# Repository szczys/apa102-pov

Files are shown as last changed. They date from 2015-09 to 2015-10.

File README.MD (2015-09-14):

APA102-POV
==========

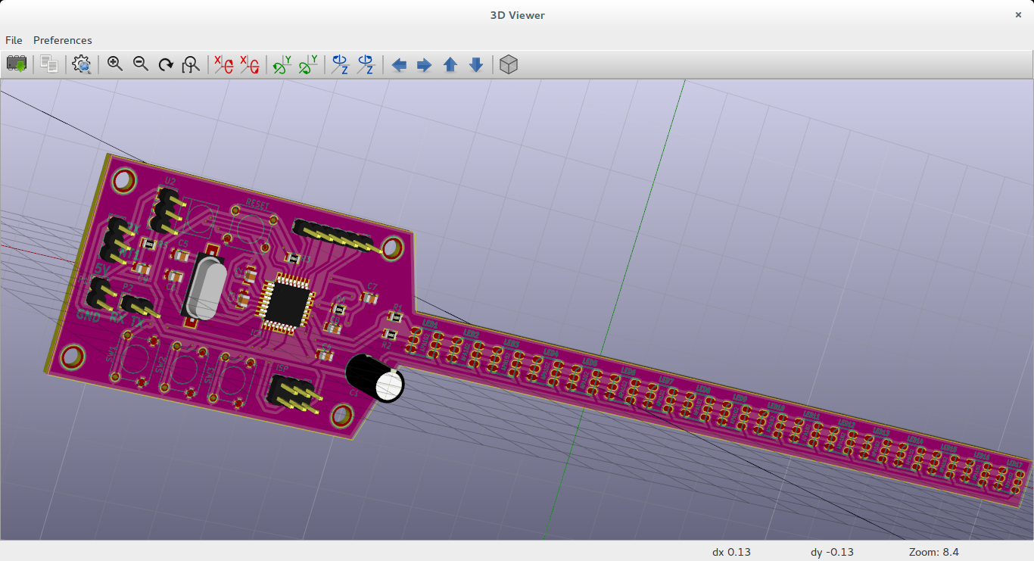
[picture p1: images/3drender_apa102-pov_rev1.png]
3D Render of APA102-POV board Revision 1


This is a persistence of vision display using the APA102 RGB LED modules. I whipped this design up on the spot at Anool Mahidharia's KiCAD workshop (I hadn't relaly planned ahead to have a design ready). It is untested and definitely a work in progress.

Features:
---------

* 17 RGB Pixels (2 rows of 5x7 characters with a row in between and on either edge)
* IR receiver to issue commands as the display spins
* Hall effect sensor to know precisely where/when each revolution begins

TODO:
-----

* Figure out a method to spin this display
* Find a 5V supply for this board
* Write the code

Future Additions:
-----------------

* I broke out RX/TX pins. It would be fun to add an ESP8266 module to make it WiFi connected
* Power transfer from the base which probably means I need a second regulator circuit

License:
--------

Hardware design is by Mike Szczys and licensed [CC-BY-SA 3.0](https://creativecommons.org/licenses/by-sa/3.0/us/)

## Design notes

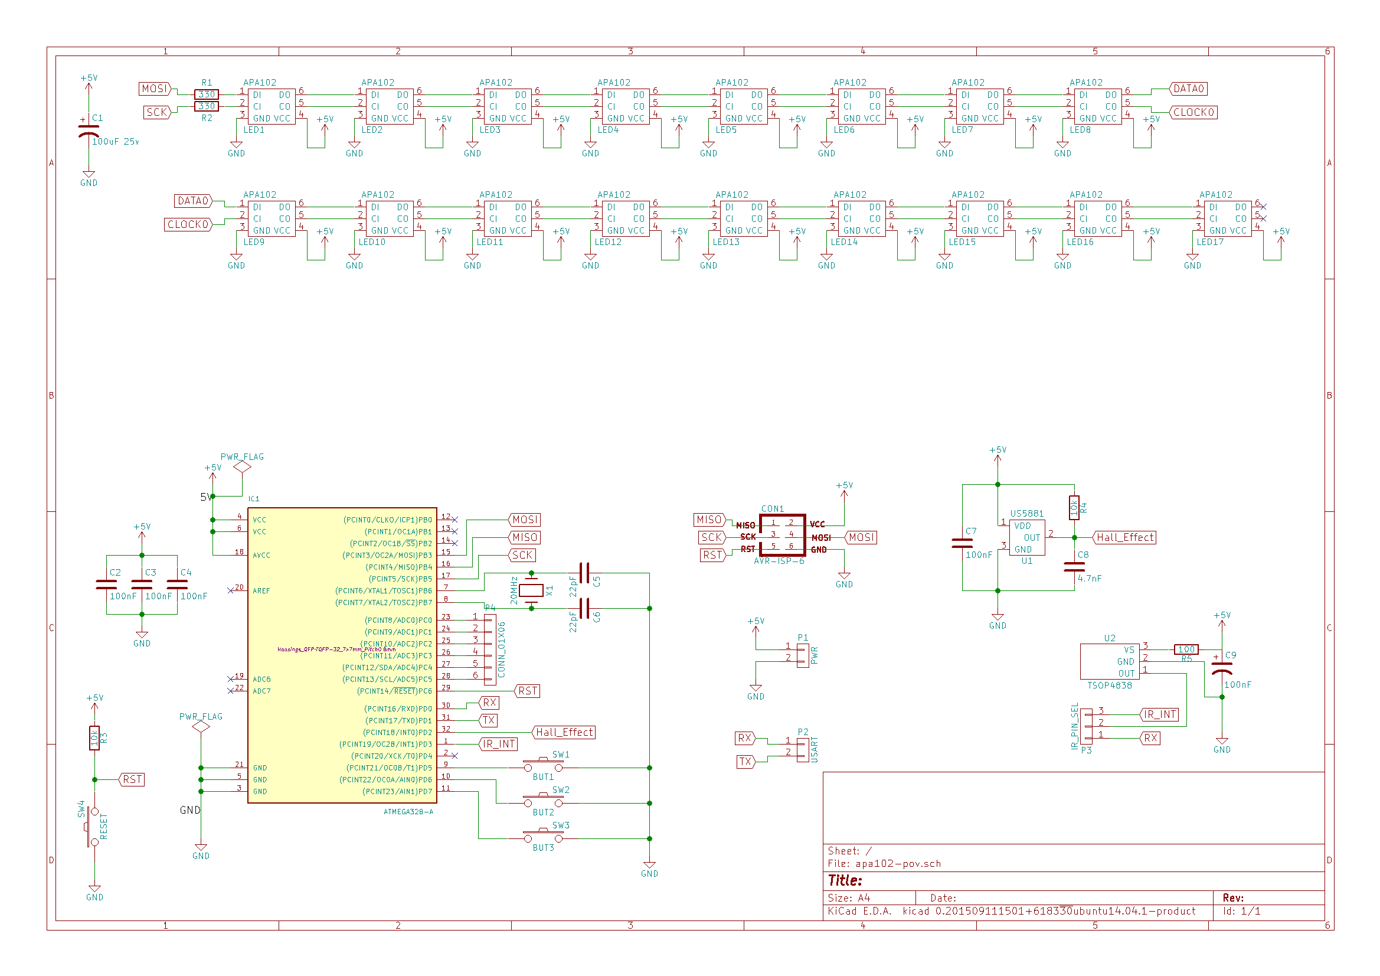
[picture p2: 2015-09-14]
images/schematic_apa102-pov_rev1.png

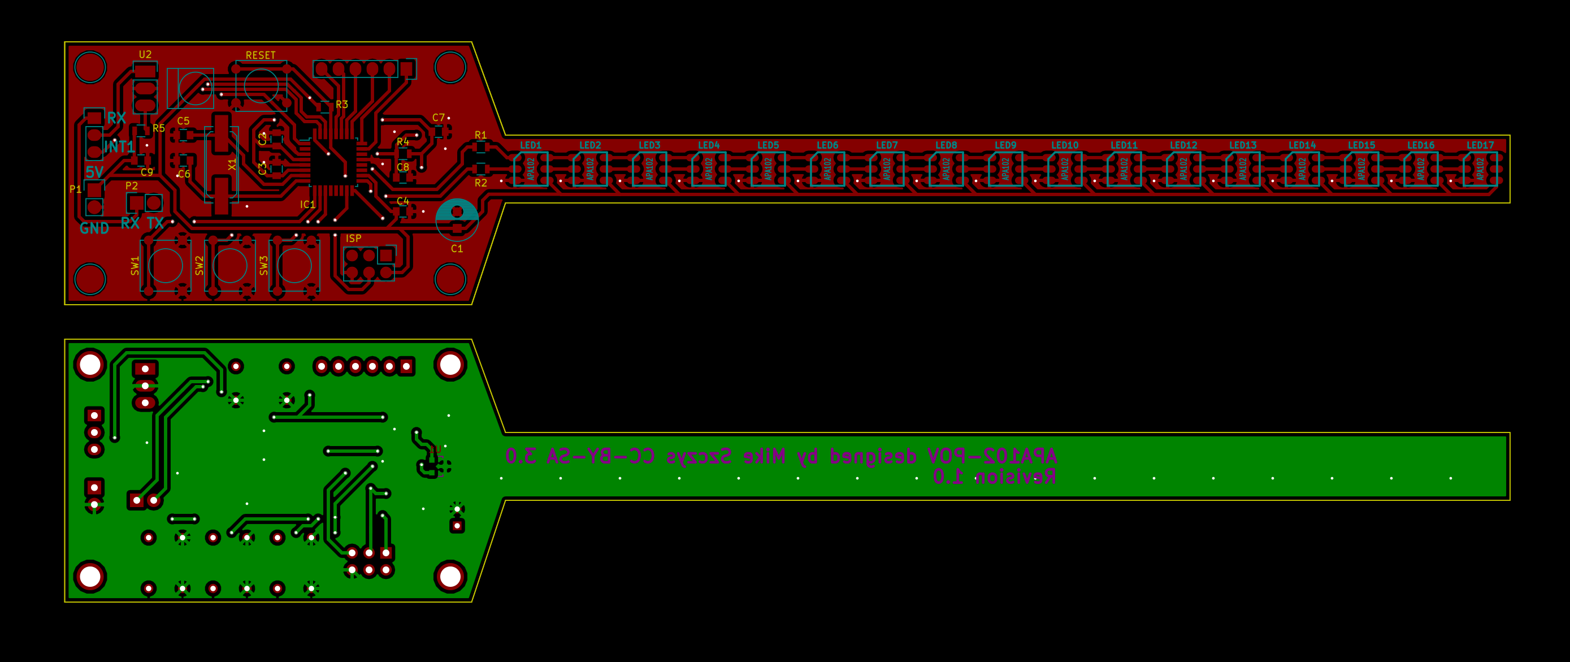
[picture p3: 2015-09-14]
images/boardlayout_apa102-pov_rev1.png

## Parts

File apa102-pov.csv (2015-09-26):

Reference | Value | Footprint | Datasheet | Digikey
IC1 | ATMEGA328-A | Housings_QFP:TQFP-32_7x7mm_Pitch0.8mm
X1 | 20MHz | Crystals_Oscillators_SMD:Q_49U3HMS
C5 | 22pF | Capacitors_SMD:C_0805
C6 | 22pF | Capacitors_SMD:C_0805
C4 | 100nF | Capacitors_SMD:C_0805
C3 | 100nF | Capacitors_SMD:C_0805
C2 | 100nF | Capacitors_SMD:C_0805
LED1 | APA102 | APA102:APA102 | DOCUMENTATION
LED2 | APA102 | APA102:APA102 | DOCUMENTATION
LED3 | APA102 | APA102:APA102 | DOCUMENTATION
LED4 | APA102 | APA102:APA102 | DOCUMENTATION
LED5 | APA102 | APA102:APA102 | DOCUMENTATION
LED6 | APA102 | APA102:APA102 | DOCUMENTATION
LED7 | APA102 | APA102:APA102 | DOCUMENTATION
LED8 | APA102 | APA102:APA102 | DOCUMENTATION
LED9 | APA102 | APA102:APA102 | DOCUMENTATION
LED10 | APA102 | APA102:APA102 | DOCUMENTATION
LED11 | APA102 | APA102:APA102 | DOCUMENTATION
LED12 | APA102 | APA102:APA102 | DOCUMENTATION
LED13 | APA102 | APA102:APA102 | DOCUMENTATION
LED14 | APA102 | APA102:APA102 | DOCUMENTATION
LED15 | APA102 | APA102:APA102 | DOCUMENTATION
LED16 | APA102 | APA102:APA102 | DOCUMENTATION
LED17 | APA102 | APA102:APA102 | DOCUMENTATION
C1 | 100uF 25v | Capacitors_SMD:c_elec_6.3x5.3 | http://nichicon-us.com/english/products/pdfs/e-wx.pdf | http://www.digikey.com/product-detail/en/UWX1E101MCL1GB/493-2113-1-ND/590088
R1 | 330 | Resistors_SMD:R_0805
R2 | 330 | Resistors_SMD:R_0805
R3 | 10k | Resistors_SMD:R_0805
SW4 | RESET | Buttons_Switches_ThroughHole:SW_PUSH_SMALL
SW1 | BUT1 | Buttons_Switches_ThroughHole:SW_PUSH_SMALL
SW2 | BUT2 | Buttons_Switches_ThroughHole:SW_PUSH_SMALL
SW3 | BUT3 | Buttons_Switches_ThroughHole:SW_PUSH_SMALL
CON1 | AVR-ISP-6 | Pin_Headers:Pin_Header_Straight_2x03
U1 | US5881 | TO_SOT_Packages_SMD:SOT-23 | DOCUMENTATION
C8 | 4.7nF | Capacitors_SMD:C_0805
C7 | 100nF | Capacitors_SMD:C_0805
R4 | 10k | Resistors_SMD:R_0805
P1 | PWR | Pin_Headers:Pin_Header_Straight_1x02
P2 | USART | Pin_Headers:Pin_Header_Straight_1x02
U2 | TSOP4838 | APA102:TSOP4838 | DOCUMENTATION
C9 | 100nF | Capacitors_SMD:C_0805
R5 | 100 | Resistors_SMD:R_0805
P3 | IR_PIN_SEL | Pin_Headers:Pin_Header_Straight_1x03
P4 | CONN_01X06 | Pin_Headers:Pin_Header_Straight_1x06

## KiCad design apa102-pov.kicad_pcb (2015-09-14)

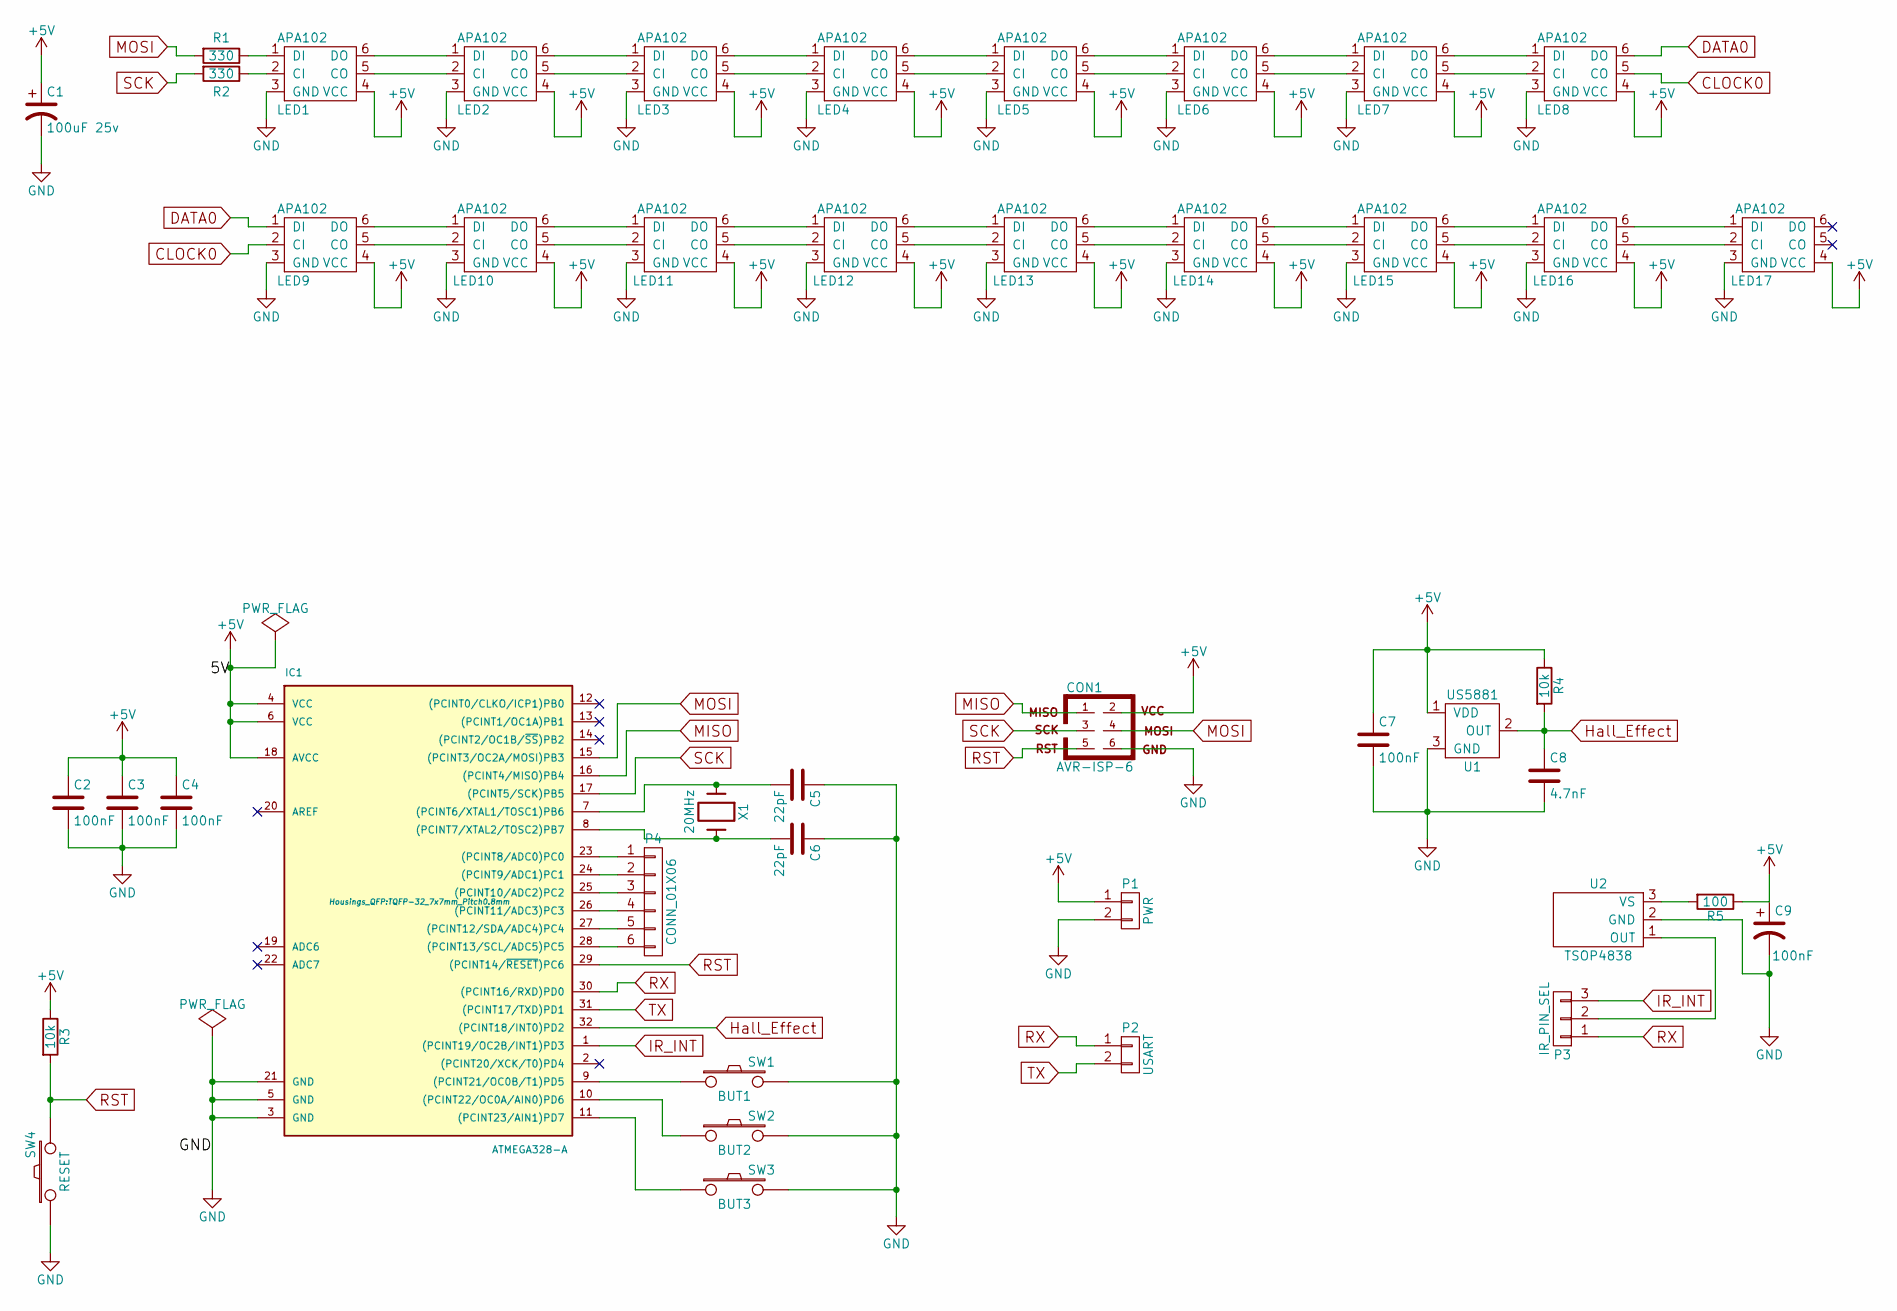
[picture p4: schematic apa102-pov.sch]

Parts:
C1: 100uF 25v; c_elec_6.3x5.3
C2, C3, C4, C7, C9: 100nF; C_0805
C5, C6: 22pF; C_0805
C8: 4.7nF; C_0805
CON1: AVR-ISP-6; Pin_Header_Straight_2x03
IC1: ATMEGA328-A; TQFP-32_7x7mm_Pitch0.8mm
LED1, LED2, LED3, LED4, LED5, LED6, LED7, LED8, LED9, LED10, LED11, LED12, LED13, LED14, LED15, LED16, LED17: APA102
P1: PWR; Pin_Header_Straight_1x02
P2: USART; Pin_Header_Straight_1x02
P3: IR_PIN_SEL; Pin_Header_Straight_1x03
P4: CONN_01X06; Pin_Header_Straight_1x06
R1, R2: 330; R_0805
R3, R4: 10k; R_0805
R5: 100; R_0805
SW1: BUT1; SW_PUSH_SMALL
SW2: BUT2; SW_PUSH_SMALL
SW3: BUT3; SW_PUSH_SMALL
SW4: RESET; SW_PUSH_SMALL
U1: US5881; SOT-23
U2: TSOP4838
X1: 20MHz; Q_49U3HMS

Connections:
+5V: C1.1, C2.1, C3.1, C4.1, C7.1, C9.1, CON1.2, IC1.4 (VCC), IC1.6 (VCC), IC1.18 (AVCC), LED1.4 (VCC), LED2.4 (VCC), LED3.4 (VCC), LED4.4 (VCC), LED5.4 (VCC), LED6.4 (VCC), LED7.4 (VCC), LED8.4 (VCC), LED9.4 (VCC), LED10.4 (VCC), LED11.4 (VCC), LED12.4 (VCC), LED13.4 (VCC), LED14.4 (VCC), LED15.4 (VCC), LED16.4 (VCC), LED17.4 (VCC), P1.1, R3.1, R4.1, R5.1, U1.1 (VDD); also elsewhere on the board
CLOCK0: LED8.5 (CO), LED9.2 (CI)
DATA0: LED8.6 (DO), LED9.1 (DI)
GND: C1.2, C2.2, C3.2, C4.2, C5.1, C6.1, C7.2, C8.2, C9.2, CON1.6, IC1.3 (GND), IC1.5 (GND), IC1.21 (GND), LED1.3 (GND), LED2.3 (GND), LED3.3 (GND), LED4.3 (GND), LED5.3 (GND), LED6.3 (GND), LED7.3 (GND), LED8.3 (GND), LED9.3 (GND), LED10.3 (GND), LED11.3 (GND), LED12.3 (GND), LED13.3 (GND), LED14.3 (GND), LED15.3 (GND), LED16.3 (GND), LED17.3 (GND), P1.2, SW1.2, SW2.2, SW3.2, SW4.1, U1.3 (GND), U2.2 (GND); also elsewhere on the board
Hall_Effect: C8.1, IC1.32 ((PCINT18/INT0)PD2), R4.2, U1.2 (OUT)
IR_INT: IC1.1 ((PCINT19/OC2B/INT1)PD3), P3.3
MISO: CON1.1, IC1.16 ((PCINT4/MISO)PB4); also elsewhere on the board
MOSI: CON1.4, IC1.15 ((PCINT3/OC2A/MOSI)PB3), R1.2; also elsewhere on the board
unnamed: C5.2, IC1.7 ((PCINT6/XTAL1/TOSC1)PB6), X1.1
unnamed: C6.2, IC1.8 ((PCINT7/XTAL2/TOSC2)PB7), X1.2
unnamed: IC1.9 ((PCINT21/OC0B/T1)PD5), SW1.1
unnamed: IC1.10 ((PCINT22/OC0A/AIN0)PD6), SW2.1
unnamed: IC1.11 ((PCINT23/AIN1)PD7), SW3.1
unnamed: IC1.23 ((PCINT8/ADC0)PC0), P4.1
unnamed: IC1.24 ((PCINT9/ADC1)PC1), P4.2
unnamed: IC1.25 ((PCINT10/ADC2)PC2), P4.3
unnamed: IC1.26 ((PCINT11/ADC3)PC3), P4.4
unnamed: IC1.27 ((PCINT12/SDA/ADC4)PC4), P4.5
unnamed: IC1.28 ((PCINT13/SCL/ADC5)PC5), P4.6
unnamed: LED1.1 (DI), R1.1
unnamed: LED1.2 (CI), R2.1
unnamed: LED1.5 (CO), LED2.2 (CI)
unnamed: LED1.6 (DO), LED2.1 (DI)
unnamed: LED2.5 (CO), LED3.2 (CI)
unnamed: LED2.6 (DO), LED3.1 (DI)
unnamed: LED3.5 (CO), LED4.2 (CI)
unnamed: LED3.6 (DO), LED4.1 (DI)
unnamed: LED4.5 (CO), LED5.2 (CI)
unnamed: LED4.6 (DO), LED5.1 (DI)
unnamed: LED5.5 (CO), LED6.2 (CI)
unnamed: LED5.6 (DO), LED6.1 (DI)
unnamed: LED6.5 (CO), LED7.2 (CI)
unnamed: LED6.6 (DO), LED7.1 (DI)
unnamed: LED7.5 (CO), LED8.2 (CI)
unnamed: LED7.6 (DO), LED8.1 (DI)
unnamed: LED9.6 (DO), LED10.1 (DI)
unnamed: LED9.5 (CO), LED10.2 (CI)
unnamed: LED10.5 (CO), LED11.2 (CI)
unnamed: LED10.6 (DO), LED11.1 (DI)
unnamed: LED11.5 (CO), LED12.2 (CI)
unnamed: LED11.6 (DO), LED12.1 (DI)
unnamed: LED12.5 (CO), LED13.2 (CI)
unnamed: LED12.6 (DO), LED13.1 (DI)
unnamed: LED13.5 (CO), LED14.2 (CI)
unnamed: LED13.6 (DO), LED14.1 (DI)
unnamed: LED14.5 (CO), LED15.2 (CI)
unnamed: LED14.6 (DO), LED15.1 (DI)
unnamed: LED15.5 (CO), LED16.2 (CI)
unnamed: LED15.6 (DO), LED16.1 (DI)
unnamed: LED16.5 (CO), LED17.2 (CI)
unnamed: LED16.6 (DO), LED17.1 (DI)
unnamed: P3.2, U2.1 (OUT)
unnamed: R5.2, U2.3 (VS)
RST: CON1.5, IC1.29 ((PCINT14/~RESET~)PC6), R3.2, SW4.2; also elsewhere on the board
RX: IC1.30 ((PCINT16/RXD)PD0), P2.1, P3.1
SCK: CON1.3, IC1.17 ((PCINT5/SCK)PB5), R2.2; also elsewhere on the board
TX: IC1.31 ((PCINT17/TXD)PD1), P2.2

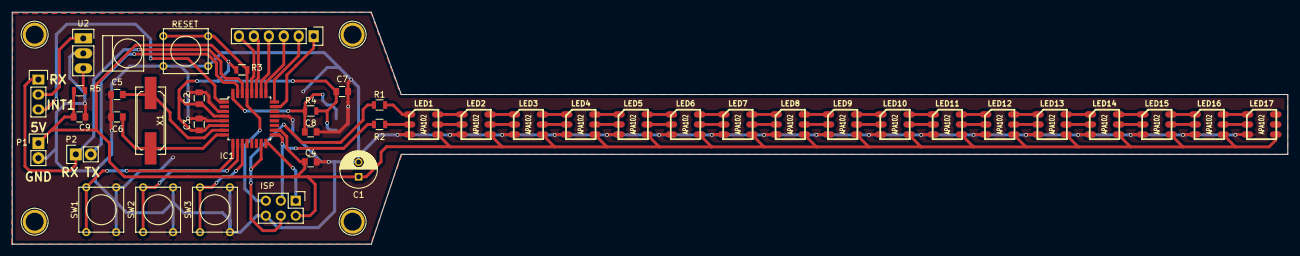
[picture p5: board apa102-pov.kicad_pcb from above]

Board: 2 copper layers, 216.5 x 39.4 mm, 44 parts (1 on the bottom side), 57 nets.

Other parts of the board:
ISP: AVR-ISP-6; Pin_Header_Straight_2x03
RESET: RESET; SW_PUSH_SMALL

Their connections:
+5V: ISP.2; also elsewhere on the board
GND: ISP.6, RESET.1; also elsewhere on the board
MISO: ISP.1; also elsewhere on the board
MOSI: ISP.4; also elsewhere on the board
RST: ISP.5, RESET.2; also elsewhere on the board
SCK: ISP.3; also elsewhere on the board

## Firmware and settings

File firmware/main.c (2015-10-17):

/********************************
* APA102-POV                 	*
* MIT License               	*
* Copyright 2015 - Mike Szczys  *
* http://jumptuck.com 	    	*
*				                *
********************************/

#define F_CPU 20000000

//lfuse: 0b11010111
//  This is 0xD7 for:
//  -No clock divide by 8
//  -Brown-out Detector
//  -Full-swing crystal oscillator (20Mhz)


#include <avr/io.h>
#include <util/delay.h>

#define TOTPIXELS   17
struct Pixels
{
    uint8_t brightness;
    uint8_t r;
    uint8_t g;
    uint8_t b;
} pixel;

struct Pixels pixels[TOTPIXELS];

/************** Setup bitbang LEDs ********************/
#define LED_DDR     DDRB
#define LED_PORT    PORTB     
#define LED_DATA    (1<<PB3)
#define LED_CLOCK   (1<<PB5)

/************** Setup input buttons *********************/
#define BUT_DDR     DDRD
#define BUT_PORT    PORTD
#define BUT_PIN     PIND
#define BUT_SW1     (1<<PD5)
#define BUT_SW2     (1<<PD6)
#define BUT_SW3     (1<<PD7)

/**************** Prototypes *************************************/
void POST(uint8_t pixels, uint8_t brightness);
void startFrame(void);
void endFrame(void);
void pushPixel(uint8_t brightness, uint8_t r, uint8_t g, uint8_t b);
void shiftByte(uint8_t data);
void shiftZero(void);
void shiftOne(void);
void initBuffer(void);
void printBuffer(void);
void init_IO(void);
void init_interrupts(void);
void larsonScanner(uint8_t repeat);
void fadePixelsByHalf(void);
/**************** End Prototypes *********************************/

void POST(uint8_t pixels, uint8_t brightness) {
    //Bit Bang the LEDs to ensure they work despite hardware SPI
    
    uint8_t i = 0;
    startFrame();
    while (i++ <= (pixels/3)) {
        //Shift Red
        pushPixel(brightness, 0xFF, 0x00, 0x00);
        //Shift Green
        pushPixel(brightness, 0x00, 0xFF, 0x00);
        //Shift Blue
        pushPixel(brightness, 0x00, 0x00, 0xFF);
    }
    endFrame();
    
}

void startFrame(void) {
    //Start frame (0*32);
    shiftByte(0x00);    shiftByte(0x00);   shiftByte(0x00);   shiftByte(0x00);
}

void endFrame(void) {
    //End frame (1*32);
    shiftByte(0xFF);    shiftByte(0xFF);   shiftByte(0xFF);   shiftByte(0xFF);
}

void pushPixel(uint8_t brightness, uint8_t r, uint8_t g, uint8_t b) {
    //Brightness only uses 5 LSB. 3 MSB must all be 1
    shiftByte(0b11100000 | brightness);    shiftByte(b);   shiftByte(g);   shiftByte(r);
}
void shiftByte(uint8_t data) {
    for (uint8_t i=0; i<8; i++) {
        if (data & (1<<(7-i))) { shiftOne(); }
        else { shiftZero(); }
    }
}

void shiftZero(void) {
    LED_PORT &= ~LED_DATA;    //low
    LED_PORT |= LED_CLOCK;                  //Raise Clock to shift in Data
    LED_PORT &= ~LED_CLOCK;                  //Clock low
}

void shiftOne(void) {
    LED_PORT |= LED_DATA;                   //Data high
    LED_PORT |= LED_CLOCK;                  //Raise Clock to shift in Data
    LED_PORT &= ~LED_CLOCK;                  //Clock low
}

void initBuffer(void) {
    for (uint8_t i=0; i<TOTPIXELS; i++) {
        pixels[i].brightness = 31;
        pixels[i].r = 0;
        pixels[i].g = 0;
        pixels[i].b = 0;
    }
}

void printBuffer(void) {
    startFrame();
    for (uint8_t i=0; i<TOTPIXELS; i++) {
        pushPixel(pixels[i].brightness, pixels[i].r, pixels[i].g, pixels[i].b);
    }
    endFrame();
}

void init_IO(void) {
    //BitBang LEDS
    LED_DDR |= LED_DATA | LED_CLOCK;
    LED_PORT &= ~(LED_DATA | LED_CLOCK);       //start low
    
    //Buttons
    BUT_DDR &= ~(BUT_SW1 | BUT_SW2 | BUT_SW3);      //Set as input
    BUT_PORT |= BUT_SW1 | BUT_SW2 | BUT_SW3;      //Enable pull-up
}

void init_interrupts(void) {

}

void fadeForever(void) {
    uint8_t fade = 0;
    while(1)
    {
        if (++fade > 31) { fade = 0; }
        startFrame();
        pushPixel(fade, 0xFF, 0x00, 0x00);
        pushPixel(fade, 0x00, 0xFF, 0x00);
        pushPixel(fade, 0x00, 0x00, 0xFF);
        endFrame();
        _delay_ms(20);
    }
}

void rainbowForever(uint8_t pixels, uint8_t brightness, uint8_t repeat) {    
    uint8_t cycleRed = 0xFF;
    uint8_t cycleGreen = 0;
    uint8_t cycleBlue = 0;
    uint8_t cycles = repeat;
    
    if (repeat == 0) { cycles = 1;}

    while(cycles > 0)
    {
        if (repeat == 0) {
            cycles = 1;
        }
        else { --cycles; }
        //down red
        
        while (cycleRed > 0) {
            cycleRed -= 1;
            cycleGreen = 0xFF - cycleRed;
        
            startFrame();
            for (uint8_t i=0; i<pixels; i++) { pushPixel(brightness, cycleRed, cycleGreen, cycleBlue); }
            endFrame();

            _delay_ms(2);
        }
        
        //down green
        while (cycleGreen > 0) {
            cycleGreen -= 1;
            cycleBlue = 0xFF - cycleGreen;
        
            startFrame();
            for (uint8_t i=0; i<pixels; i++) { pushPixel(brightness, cycleRed, cycleGreen, cycleBlue); }
            endFrame();

            _delay_ms(2);
        }

        //down blue
        while (cycleBlue > 0) {
            cycleBlue -= 1;
            cycleRed = 0xFF - cycleBlue;
        
            startFrame();
            for (uint8_t i=0; i<pixels; i++) { pushPixel(brightness, cycleRed, cycleGreen, cycleBlue); }
            endFrame();

            _delay_ms(2);
        }     
    }
}

void larsonScanner(uint8_t repeat) {
    int8_t dir = 1;    //direction
    uint8_t idx = 0;    //index
    uint8_t pixStart = 128; //pixelStartValue
    uint8_t cycles = repeat;
    
    initBuffer();
    pixels[idx].r = pixStart; //light the first pixel
    printBuffer();
    
    if (repeat == 0) {
        // 0 is code for loop forever
        cycles = 1;
    }
    
    while (cycles > 0) {
        
        idx += dir; //Increment the index
        
        //If we're not at one end or the other react accordingly
        if (idx == 0) {
            if (repeat == 0) {
                // 0 is code for loop forever
                cycles = 1;
            }
            else { --cycles; }
            dir = 1;
        }
        if (idx == (TOTPIXELS-1)) { dir = -1; }
        
        //Fade the tail before writing new pixel
        fadePixelsByHalf();
        
        //Write the new pixel
        pixels[idx].r = pixStart;
        
        //Show the changes we've made to the buffer
        printBuffer();
        
        //Delay before next loop
        _delay_ms(20);
    }
}

void fadePixelsByHalf(void) {
    for (uint8_t i=0; i<TOTPIXELS; i++) {
        pixels[i].r = pixels[i].r/2;
        pixels[i].g = pixels[i].g/2;
        pixels[i].b = pixels[i].b/2;
    }
}

int main(void)
{
    init_IO();
    init_interrupts();

    _delay_ms(200);

    POST(TOTPIXELS, 31);
    
    while (BUT_PIN & BUT_SW3) {
        ; //Loop until the button is pressed
    }

    while(1)
    {
        //fadeForever();
        rainbowForever(17, 5, 3);
        
        larsonScanner(4);
    }
}

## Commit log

2015-09-14 Added images of schematic, board, and render
2015-09-26 Added BOM
    [apa102-pov.csv]
2015-10-12 Fixed SPI clock function when shifting data
    [main.c]
2015-10-12 Added functions for all APA102 frame types
2015-10-14 Implemented a frame buffer

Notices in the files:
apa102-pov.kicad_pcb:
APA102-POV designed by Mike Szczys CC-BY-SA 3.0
